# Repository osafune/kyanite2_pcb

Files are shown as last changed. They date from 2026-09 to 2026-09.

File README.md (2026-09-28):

# DE0-nano/DE10-Lite用 I/O拡張ボード
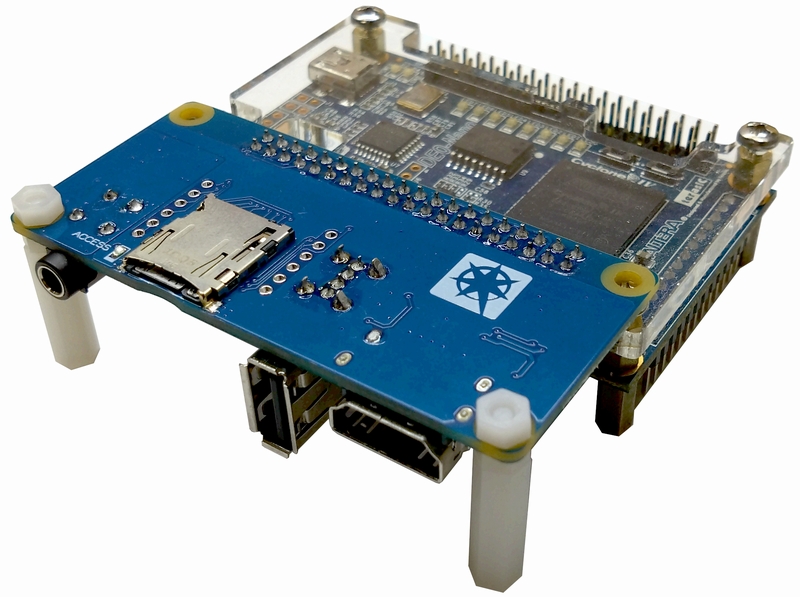
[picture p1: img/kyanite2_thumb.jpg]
KYANITE2_PCB

本ボードは、Terasic DE0-nanoおよびDE0-Liteボードに映像出力、USB、microSDおよびアナログ音声を追加するI/O拡張ボードです。  
Terasic 40ピンGPIOコネクタで FPGA ボードと接続し、HDMI出力、USB 2.0 フルスピード/ロースピード・ホスト機能、microSD カードスロット、ステレオ・ライン出力を提供します。

## 内容物

|内容物|数量|
|---|---|
|KYANITE2_PCB|1|
|M3-20mm 樹脂スペーサー|2|
|M3樹脂ナット|4||

## 使用許諾、ライセンスおよび免責
**本ボードについて下記事項を了承の上で使用してください。**
- 直射日光に晒される場所、高温や低温になる場所、結露・氷結の発生する場所、過度の衝撃や振動の発生する場所で使用しないでください。
- 本ボードは試作およびホビー用として設計されています。一般製品を意図した逆接続、逆挿入、過電圧等の保護はされていません。誤った使用は破損、発煙、発火の原因となります。
- 本ボードを使用して発生した直接的、間接的損害について開発元および販売元は一切の責務を負いません。
- 本ボードの内容および使用、測定データ、技術情報、サポート等に関してのお問い合わせは原則としてお答え致しかねます。
- 部品調達や性能改善に伴い、予告なく仕様または部品の変更を行う場合があります。
- このリポジトリのソフトウェアおよび付属ドキュメントは [MIT License](LICENSE) で提供されます。ハードウェアの製作・改造・使用は利用者自身の責任で行ってください。本ボードおよび設計データは現状有姿で提供され、商品性、特定目的への適合性、権利非侵害を含む保証はありません。

## 対応ボードと開発環境

|項目|内容|
|---|---|
|接続先|Terasic DE0-nano（Cyclone IV E）、DE10-Lite（MAX 10）|
|接続コネクタ|GPIO 2 x 20 ピン|
|設計環境|Quartus Prime 20.1 以降|

サンプル・プロジェクトは `project/de0nano/` にあります。DE10-Lite で使用する場合は、ターゲット・デバイス、ピン割当、タイミング制約を対象ボードに合わせて確認・調整してください。

## 主な機能

|機能|コネクタ/実装|概要|
|---|---|---|
|映像出力|HDMI Type-A (`CN2`)|TMDS データ 3 ペア + クロック 1 ペア。DDC（EDID）および HPD 信号を接続。|
|USB ホスト|USB Type-A (`CN3`)|USB 2.0 LS/FS ホスト。VUSBはFPGAボードの5Vを電源スイッチで制御。|
|ストレージ|microSD スロット (`CN4`、基板裏面)|1bit-SPIモードおよび4bit-SDモード対応。カード検出および電源制御を接続。|
|音声出力|φ3.5 mm ステレオジャック (`CN1`)|アナログ・ライン出力。PWMおよび1bit⊿Σ出力時のスイング幅は約 1.5 Vp-p。|
|アクセス表示| LED (`LED1`)|`ACCESS` 信号で駆動。|
|Ethernet（任意）|WIZ850io 実装用フットプリント (`U1`)|WIZ850io をオプション実装可能。SPI と割り込み/リセットを使用。|
|外部クロック|`OSC1`|`EXTCLK` 48.000 MHz を供給。|

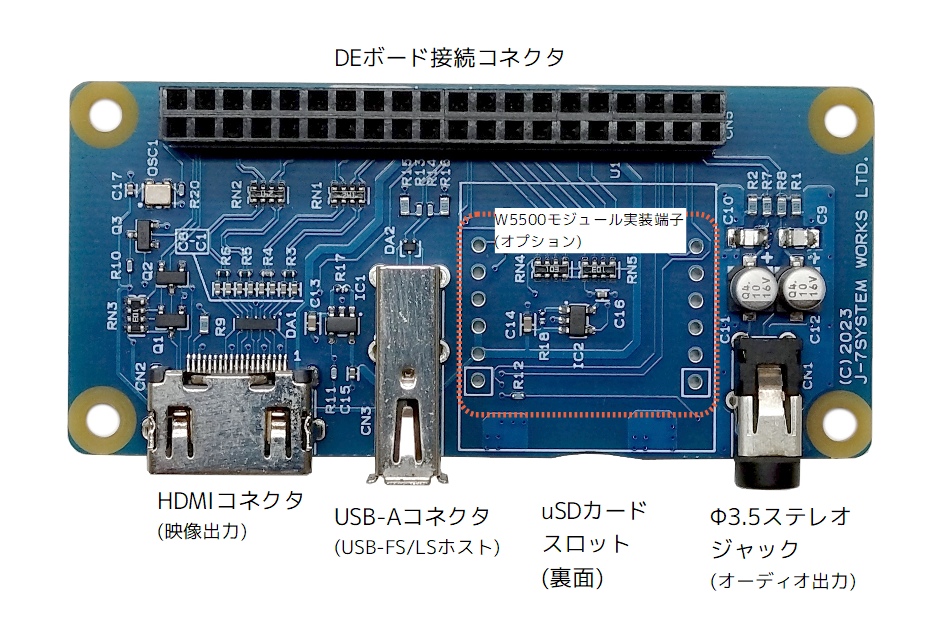
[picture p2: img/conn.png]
KYANITE2 PCB のコネクタ配置


## DE0-nanoへの取り付け

KYANITE2 PCB は **DE0-nano の GPIO1 側**に取り付けます。40 ピン・ヘッダの向きと、基板の取付穴位置を確認して、無理な力を加えずに装着してください。

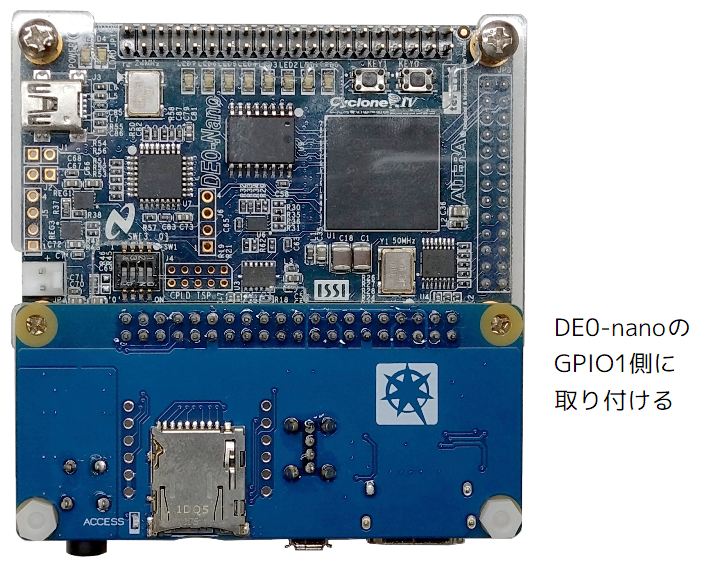
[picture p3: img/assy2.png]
DE0-nano への取り付け例


高さを合わせるために、同梱のM3-20樹脂スペーサーとナットを以下の取付図のように組み付けてください。
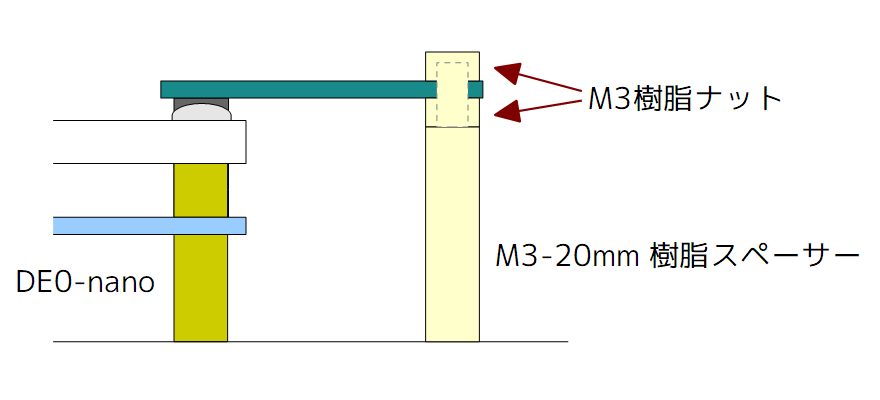
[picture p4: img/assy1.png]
スペーサーの取り付け例


## 回路図
[kyanite2_pcb_revA_schem.pdf](pcb/kyanite2_pcb_revA_schem.pdf) 

## 電源と電気的な注意

- TMDS 信号の安定性のため、次の端子を GND 出力に設定してください。
`D2`、`D4`、`D10`、`D12`
- USB VBUS と microSD の電源は、それぞれ `AP22816BKB` 電源スイッチで制御されます。電源をONにするには FPGA 側で `/VUSB_EN`、`/PWR_EN` を`L`レベルに駆動してください。
- HDMI の DDC は双方向信号です。レベル変換回路を介して FPGA の 3.3V I/O 信号に接続されています。
- アナログ音声出力は、FPGA からの `AUD_L`/`AUD_R` を RC フィルタと DC カット用コンデンサを通して出力します。1.5 Vp-pのラインレベル出力で、ヘッドホンやスピーカーの駆動はできません。
- USB は LS/FS 用です。USB High-Speed 動作は対象外です。
- WIZ850io は未実装でも、HDMI、USB、microSD、音声出力の基本機能には影響しません。

## サンプル・プロジェクト

|ディレクトリ|内容|
|---|---|
|`de0nano_blank/`|KYANITE2 の I/O を定義した最小構成のテンプレート|
|`de0nano_hdmi/`|HDMI 映像出力テスト|
|`de0nano_wavplayer/`|microSD 上の WAV ファイル再生、映像表示および音声出力のサンプル|

またIPコアはこちらも参考してください。
- ローエンドFPGA向け HDMI-TX IPコア [github.com/osafune/hdmi_tx](https://github.com/osafune/hdmi_tx)
- PERIDOTペリフェラル [github.com/osafune/peridot_peripherals](https://github.com/osafune/peridot_peripherals)

---

c 2026 PERIDOT CRAFT / J-7SYSTEM WORKS LIMITED.

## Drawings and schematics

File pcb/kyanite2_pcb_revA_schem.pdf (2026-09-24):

# ディスプレイ、USB、カード、オーディオI/F

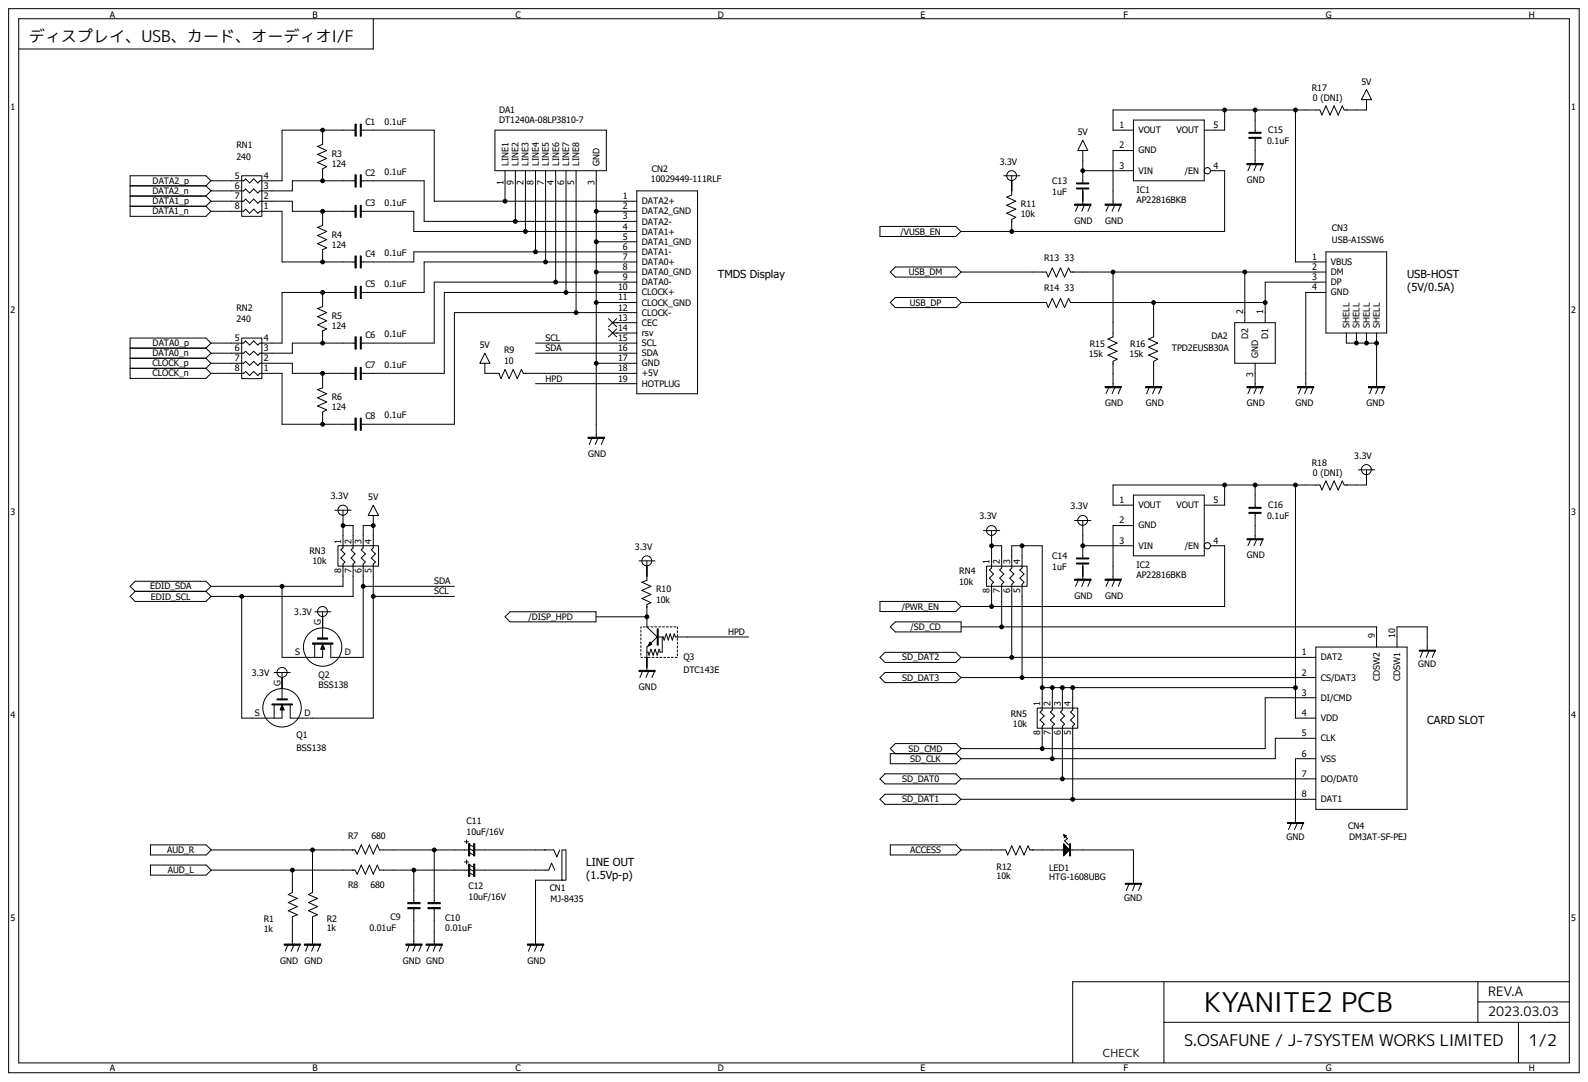
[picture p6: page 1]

SCL 5V | 13 14 15

12 | | USB_DP

SD_CLK | 7

# コネクタ

## - DE0-nanoでは以下の端子はVREFピンのため、高速信号は配置しない

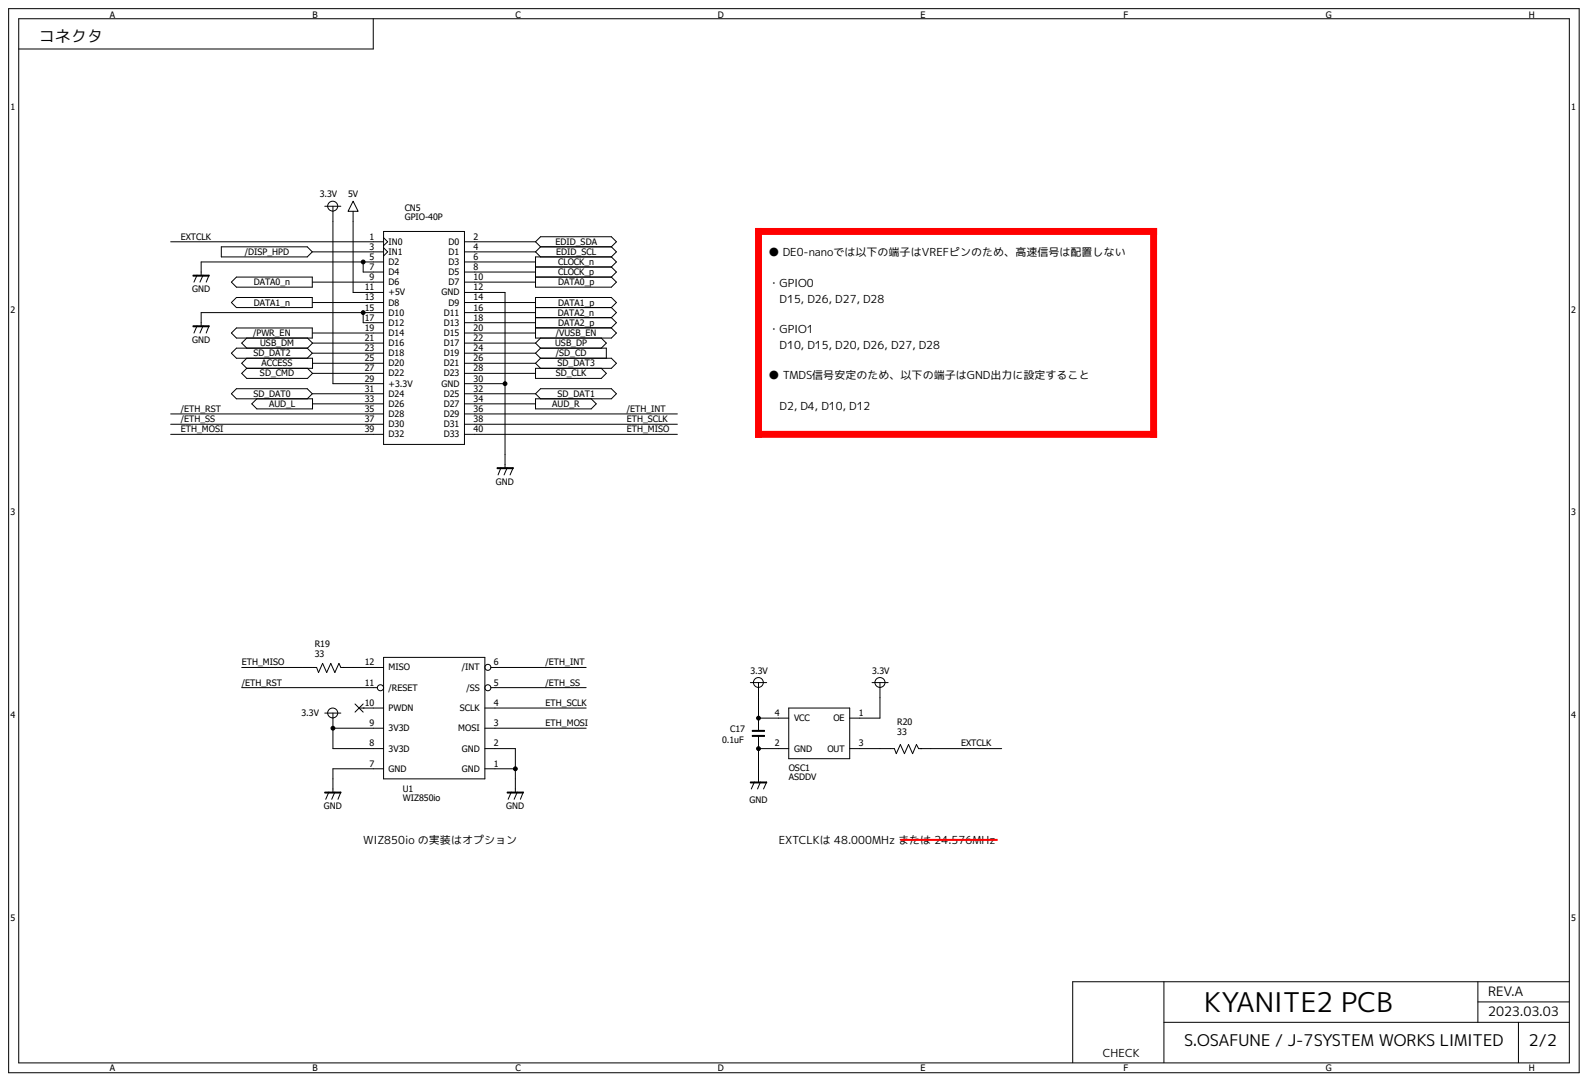
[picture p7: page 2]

5 | 6 | CLOCK_n
7 | | 8 | CLOCK_p

15 | | 16 | | DATA1_p
17 | | 18 | | DATA2_n
21 | 22 | | /VUSB_EN
23 | 24 | USB_DP
25 | | 26 | SD_DAT3
27 | | 28 | | SD_CLK
29 | | 30

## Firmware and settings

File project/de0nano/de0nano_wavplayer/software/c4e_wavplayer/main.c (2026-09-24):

/* PERIDO-Air基板サンプル：WAVファイルプレイヤー           */
/*                                                         */
/*   The MIT License (MIT)                                 */
/*   Copyright (c) 2023 J-7SYSTEM WORKS LTD.               */
/*   http://opensource.org/licenses/mit-license.php        */

// usage:
//  SDカードの /peridot/wall.bmp を壁紙に表示する。 
//  BMPファイルは1280x720ピクセルの32bppまたは24bppカラーに対応。 
//  SDカードの /peridot フォルダ以下のwavファイルを順に再生する。 
//  WAVファイルは16bitデータ、2チャネルステレオ、44.1kHzサンプリングのみ対応。 

#include <stdlib.h>
#include <string.h>
#include <io.h>
#include "system.h"
#include "peridot_sdif_pff.h"

#include "sys/alt_stdio.h"
#include "xprintf.h"
#define printf(...) xprintf(__VA_ARGS__)

#include "loadbmp.h"
#include "playwav.h"
#include "getfilename.h"


// ファイルが格納されているディレクトリパス 

#define BMPFILE_NAME	"/PERIDOT/WALL.BMP"
#define WAVFILE_DIR		"/PERIDOT"

extern peridot_sdif_pff_dev peridot_sdif_pff;		// pffハンドラ 


// WAVプレイヤー 

static char playfile[13 + sizeof(WAVFILE_DIR) + 1];

int main(void)
{
	const alt_u32 dev_vga = VGA_BASE;

	void *pfb_top;
	alt_u16 *pfb;
	char *fn;

	// システム初期化 

	xdev_out(alt_putchar);

	IOWR(dev_vga, 0, 0);
	play_init();

	printf("\n\n"
		"-----------------------------\n"
		" PERIDOT-Air wav file player\n"
		"-----------------------------\n"
		"sysid : %08x-%08x\n",
		IORD(SYSID_BASE, 0), IORD(SYSID_BASE, 1)
	);


	// SDカード初期化 

	printf("Disk check ... ");

	if (peridot_sdif_pff.init_res != FR_OK) {
		printf("fail(%d)\n", peridot_sdif_pff.init_res);
		while(1) {}
	}
	printf("done.\n");


	// VGA初期化 

	pfb_top = malloc(VGA_VRAM_LINEBYTES * VGA_VRAM_VIEWHEIGHT + 1023);
	if (pfb_top == NULL) {
		printf("[!] Framebuffer allocation failure.\n");
		return -1;
	}
	pfb = (alt_u16 *)(((alt_u32)pfb_top + 1023) & ~0x3ffUL);

	IOWR(dev_vga, 1, (alt_u32)pfb);
	IOWR(dev_vga, 0, 1);


	// 画面初期化 

	if ( loadbmp(BMPFILE_NAME, pfb) ) {
		printf("Failed to load " BMPFILE_NAME "\n");
		while (1) {}
	}


	// wavファイルの連続再生 

	IOWR(BARCOLOR_BASE, 0, 0x222);		// 波形バーの色設定 
	play_setvol(0x2000, 0x2000);

	while(1) {
		fn = get_wavfilename();
		if (fn == NULL) {
			if ( open_wavdir(WAVFILE_DIR) ) {
				printf("[!] Directory open fail.\n");
				break;
			}
			continue;
		}

		strcpy(playfile, WAVFILE_DIR "/");
		strcat(playfile, fn);
		play_wav(playfile);

		while( play_status() ) {
//			if ( !(IORD(PSW_BASE, 0) & (1<<0)) ) {
//				play_stop();
//				while( !(IORD(PSW_BASE, 0) & (1<<0)) ) {}
//			}
		}
	}


	// 終了処理 

	IOWR(dev_vga, 0, 0);
	free(pfb_top);

	return 0;
}

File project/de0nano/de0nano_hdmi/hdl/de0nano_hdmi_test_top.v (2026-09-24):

// ===================================================================
// TITLE : CycloneIV E HDMI output sample (DE0-nano + KYANITE2)
//
//     DESIGN : s.osafune@j7system.jp (J-7SYSTEM WORKS LIMITED)
//     DATE   : 2022/12/01 -> 2023/01/02
//            : 2023/03/28
//
//
// ===================================================================
//
// The MIT License (MIT)
// Copyright (c) 2022 J-7SYSTEM WORKS LIMITED.
//
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


// Verilog-2001 / IEEE 1364-2001
`default_nettype none

module de0nano_hdmi_test_top(
	// clk and system reset
	input wire			CLOCK_50,
	input wire			EXTCLK_48,

	// KEY and LED
	input wire  [1:0]	KEY,
	input wire  [3:0]	SW,
	output wire [7:0]	LED,

	// Interface: EPCS memory controller
	output wire			EPCS_NCSO,
	output wire			EPCS_DCLK,
	output wire			EPCS_ASDO,
	input wire			EPCS_DATA0,

	// Interface: SDRAM
	output wire			DRAMCLK_OUT,
	output wire			DRAM_CKE,
	output wire			DRAM_CS_N,
	output wire			DRAM_RAS_N,
	output wire			DRAM_CAS_N,
	output wire			DRAM_WE_N,
	output wire [12:0]	DRAM_ADDR,
	output wire [1:0]	DRAM_BA,
	inout wire  [15:0]	DRAM_DQ,
	output wire [1:0]	DRAM_DQM,

	// Interface: GPIO-0
	input wire  [1:0]	GPIO_0_IN,
	inout wire  [33:0]	GPIO_0,

	// Interface: TMDS display
	output wire [2:0]	TMDS_DATA,
	output wire [2:0]	TMDS_DATA_N,
	output wire			TMDS_CLOCK,
	output wire			TMDS_CLOCK_N,
	inout wire			EDID_SCL,
	inout wire			EDID_SDA,
	input wire			DISP_HPD_N,

	// Interface: SD-card controller
	output wire			SD_CLK,
	output wire			SD_CMD,
	inout wire  [3:0]	SD_DAT,
	output wire			SD_PWREN_N,		// SD-card Power enable
	input wire			SD_CD_N,		// SD-card Detect

	// Interface: USB
	inout wire			USB_DP,
	inout wire			USB_DM,
	output wire			USB_PWREN_N,	// VUSB Power enable

	// Interface: Audio
	output wire			AUD_L,
	output wire			AUD_R,

	// Interface: Ethernet
	output wire			ETH_SS_N,
	output wire			ETH_SCLK,
	output wire			ETH_MOSI,
	input wire			ETH_MISO,
	input wire			ETH_INT_N,
	output wire			ETH_RST_N,

	// Access LED
	output wire			LED_ACCESS
);


/* ===== 外部変更可能パラメータ ========== */


/* ----- 内部パラメータ ------------------ */

//	localparam COLORSPACE	= "RGB";
//	localparam VGACLOCK_MHZ	= 25.2;
//	localparam FSCLOCK_KHZ	= 48.0;
	localparam COLORSPACE	= "BT709";
	localparam VGACLOCK_MHZ	= 74.286;
	localparam FSCLOCK_KHZ	= 44.1;

	localparam FSDIVIDER	= $unsigned(VGACLOCK_MHZ * 1000.0 / FSCLOCK_KHZ + 0.5) - 1;
	localparam FSDIVHALF	= FSDIVIDER / 2;
	localparam COUNTER_WIDTH= 11;
	localparam FSDIVNUM		= FSDIVIDER[COUNTER_WIDTH-1:0];
	localparam FSHALFNUM	= FSDIVHALF[COUNTER_WIDTH-1:0];


/* ===== ノード宣言 ====================== */

	wire			vga_clk_sig, tx_clk_sig, locked_sig, reset_sig;

	reg  [12:0]		ms_counter_reg;
	reg  [COUNTER_WIDTH-1:0] fs_counter_reg;
	reg				fs_timing_reg;
	wire			timing_1ms_sig;
	wire [15:0]		wav_chime_sig;

	wire			active_sig, vsync_sig, hsync_sig;
	wire [7:0]		cb_r_sig, cb_g_sig, cb_b_sig;
	wire			de_out_sig, vs_out_sig, hs_out_sig;
	wire [23:0]		pix_out_sig;
	wire			logo_move_sig;
	wire [23:0]		logo_color_sig;


/* ===== テスト記述 ============== */



/* ===== モジュール構造記述 ============== */

	assign {DRAMCLK_OUT,DRAM_CKE} = 2'b00;					// SDRAMを使わない場合 
	assign {EPCS_DCLK,EPCS_ASDO,EPCS_NCSO} = 3'b001;		// コンフィグROMをユーザーモードで使わない場合 
	assign {SD_CLK,SD_CMD,SD_DAT[3],SD_PWREN_N} = 4'bzzz1;	// SDカードを使わない場合 
	assign {EDID_SCL,EDID_SDA} = 2'bzz;



	///// クロックとリセット /////

generate if (VGACLOCK_MHZ == 25.2) begin
	hdmi_vgapll		// c0:25.2MHz, c1:c0x5(126.0MHz)
	u_pll (
		.areset		(1'b0),
		.inclk0		(CLOCK_50),
		.c0			(vga_clk_sig),
		.c1			(tx_clk_sig),
		.locked		(locked_sig)
	);
end
else if (VGACLOCK_MHZ == 74.286) begin
	hdmi_hdpll		// c0:74.286MHz, c1:c0x5(371.43MHz)
	u_pll (
		.areset		(1'b0),
		.inclk0		(CLOCK_50),
		.c0			(vga_clk_sig),
		.c1			(tx_clk_sig),
		.locked		(locked_sig)
	);
end
endgenerate

	assign reset_sig = ~locked_sig;
	assign LED[0] = locked_sig;



	///// サウンド生成 /////

	always @(posedge vga_clk_sig or posedge reset_sig) begin
		if (reset_sig) begin
			ms_counter_reg <= 1'd0;
			fs_counter_reg <= 1'd0;
			fs_timing_reg <= 1'b0;
		end
		else begin
			if (timing_1ms_sig) begin
				ms_counter_reg <= ms_counter_reg + 1'd1;
			end

			if (fs_counter_reg == FSDIVNUM) begin
				fs_counter_reg <= 1'd0;
				fs_timing_reg <= 1'b1;
			end
			else begin
				fs_counter_reg <= fs_counter_reg + 1'd1;

				if (fs_counter_reg == FSHALFNUM) begin
					fs_timing_reg <= 1'b0;
				end
			end

		end
	end

	melodychime #(
		.CLOCK_FREQ_HZ	($unsigned(VGACLOCK_MHZ * 1000000.0))
	)
	u_chime (
		.reset		(reset_sig),
		.clk		(vga_clk_sig),
		.start		(ms_counter_reg[12]),

		.timing_1ms	(timing_1ms_sig),
		.tempo_led	(LED[1]),
		.wave_out	(wav_chime_sig)
	);



	///// ビデオ同期信号・カラーバー生成 /////

	assign logo_move_sig = 1'b1;
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
